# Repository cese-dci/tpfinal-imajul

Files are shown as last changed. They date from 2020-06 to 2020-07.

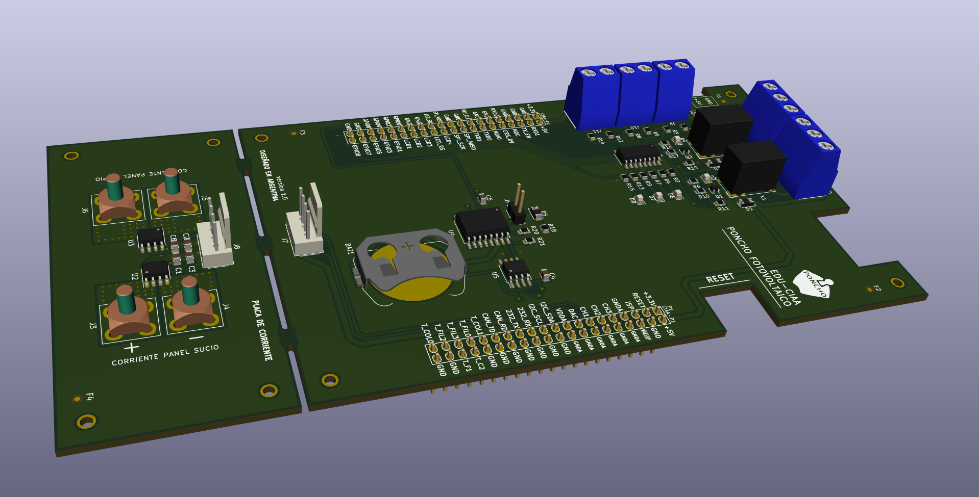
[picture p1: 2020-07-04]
PCB_3D.png

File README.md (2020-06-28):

# Diseño de circuitos impresos - TP Final

## Poncho EDU-CIAA para sistema de limpieza de paneles solares

El sistema que mide desposicion de suciedad sobre paneles en un parque solar fotovoltaico. El PCB recibe dos señales analógicas de corriente para ser procesadas, contendra salidas digitales libres de pontencial, entradas digitales, un RTC y una EEPROM sobre I2C.

### Requisitos

Este trabajo forma parte del proyecto final de especialización del autor - CESE 10ma cohorte.

## Autor

* **Ing. Ignacio Majul** - [imajul](https://github.com/imajul)

## Licencia

Este proyecto se rige bajo la licencia del Proyecto CIAA - ver license.md

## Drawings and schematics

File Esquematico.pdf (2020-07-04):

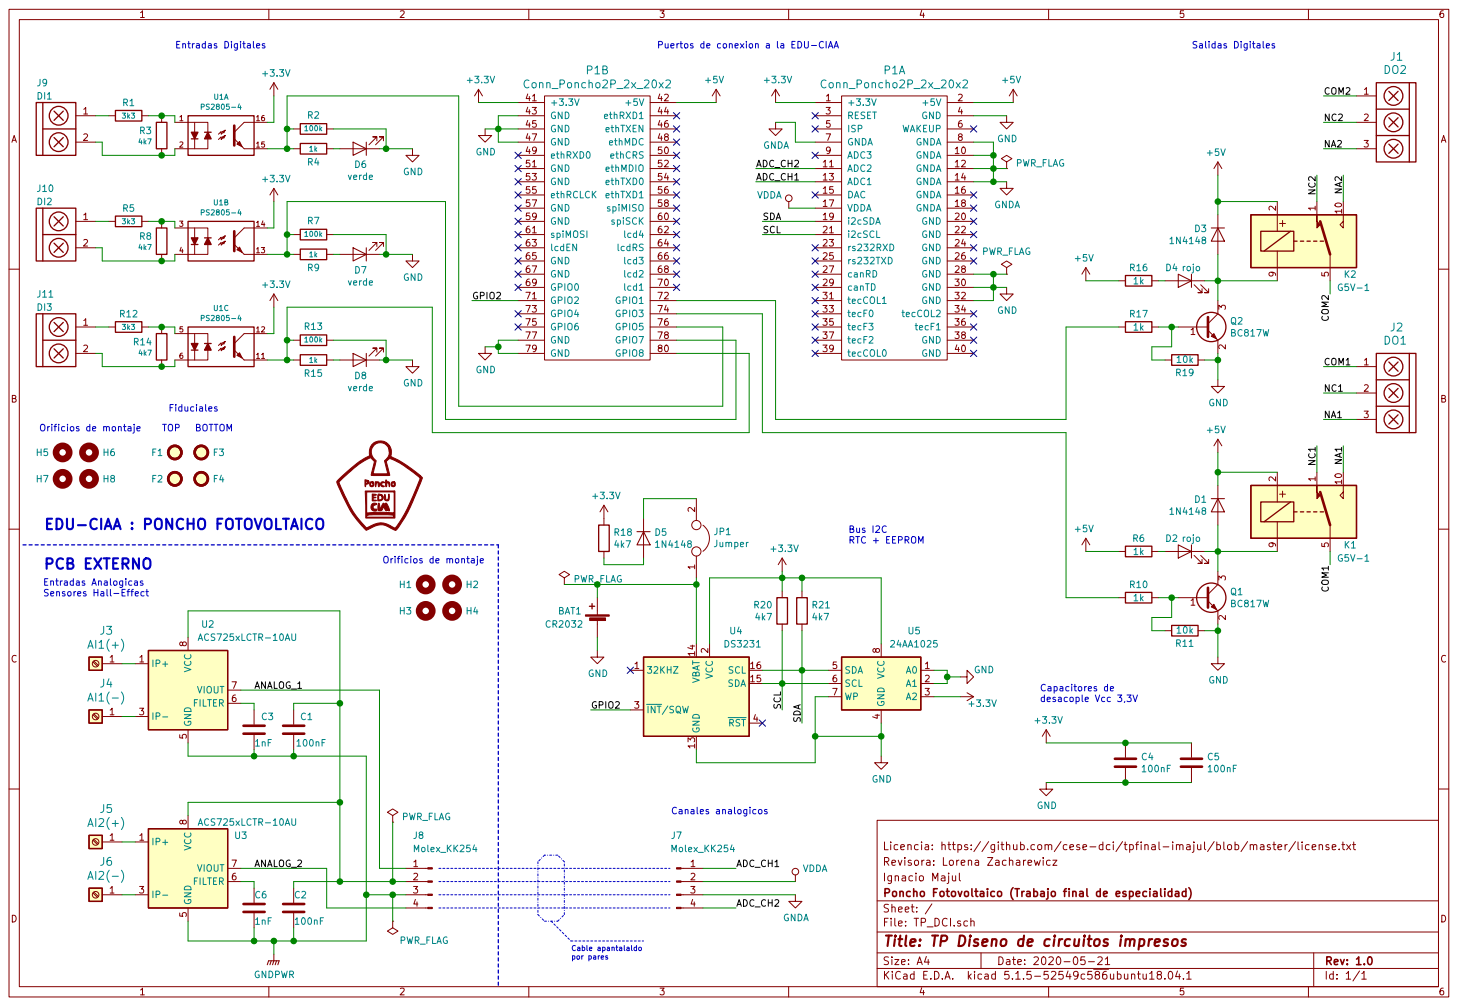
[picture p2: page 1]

EDU-CIAA : PONCHO FOTOVOLTAICO

por pares PCB EXTERNO

4 SDA 5 SCL 6 WP 7 VCC

Ignacio Majul Revisora: Lorena Zacharewicz Licencia: https://github.com/cese-dci/tpfinal-imajul/blob/master/license.txt

File: TP_DCI.sch Sheet: / Poncho Fotovoltaico (Trabajo final de especialidad)

Id: 1/1 Title: TP Diseno de circuitos impresos

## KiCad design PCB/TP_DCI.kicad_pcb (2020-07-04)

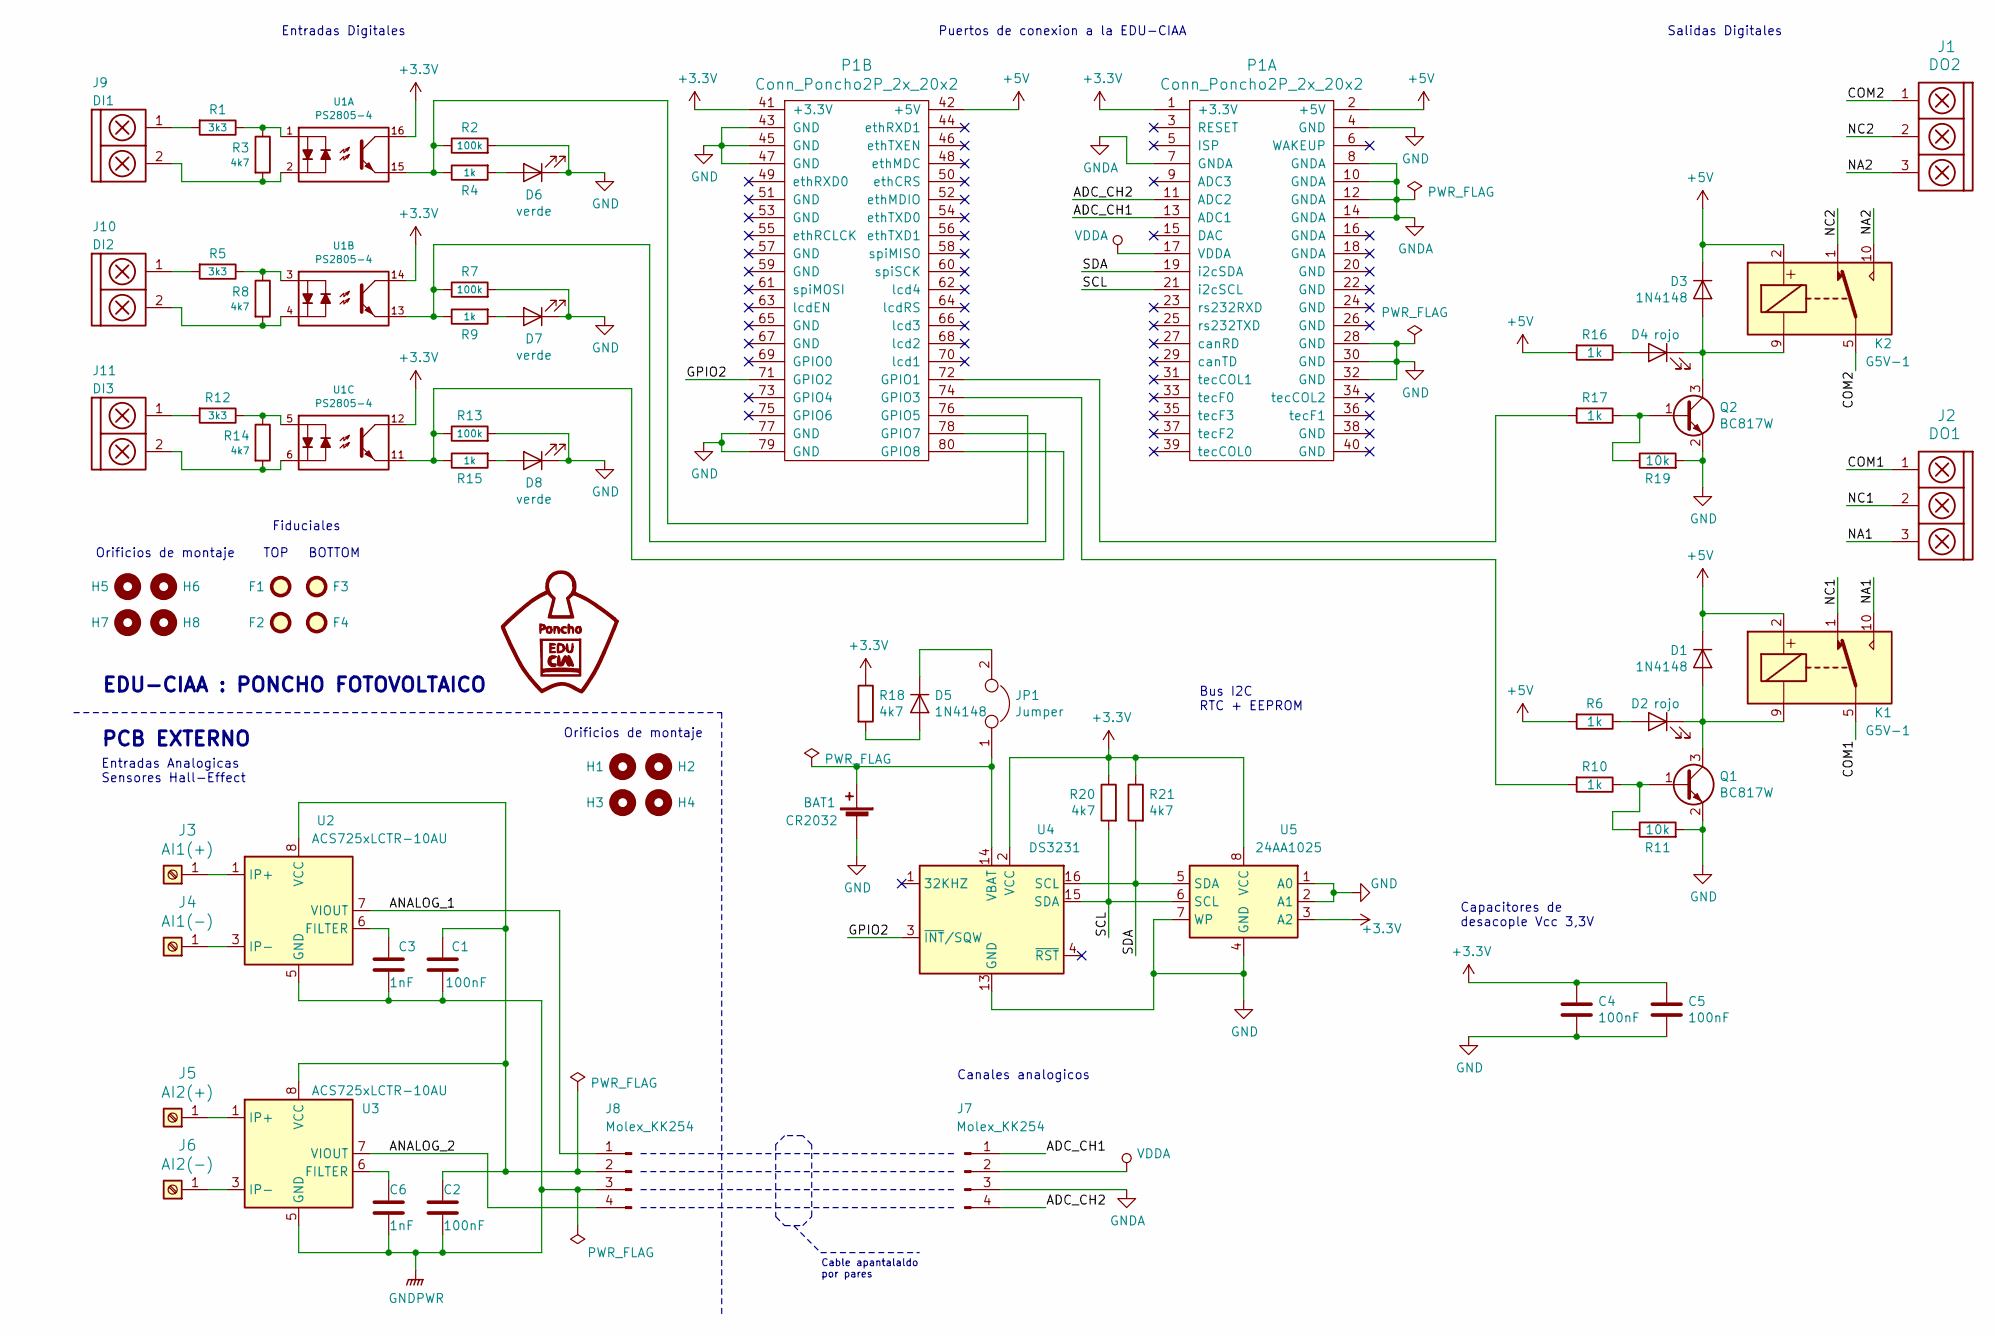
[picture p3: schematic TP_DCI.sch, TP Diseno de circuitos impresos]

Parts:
BAT1: CR2032; BatteryHolder_Keystone_3034_1x20mm
C1, C2, C4, C5: 100nF; C_0805_2012Metric
C3, C6: 1nF; C_0805_2012Metric
D1, D3, D5: 1N4148; D_1206_3216Metric
D2, D4: rojo; LED_0805_2012Metric
D6, D7, D8: verde; LED_0805_2012Metric
F1, F2, F3, F4: Fiducial; Fiducial_1mm_Mask2mm
G1: Logo_Poncho
H1, H2, H3, H4, H5, H6, H7, H8: MountingHole; MountingHole_2.1mm
J1: DO2; bornier3
J2: DO1; bornier3
J3: AI1(+); wurth_connector
J4: AI1(-); wurth_connector
J5: AI2(+); wurth_connector
J6: AI2(-); wurth_connector
J7, J8: Molex_KK254; Molex_KK-254_AE-6410-04A_1x04_P2.54mm_Vertical
J9: DI1; bornier2
J10: DI2; bornier2
J11: DI3; bornier2
JP1: Jumper; PinHeader_1x02_P2.54mm_Vertical
K1, K2: G5V-1; Relay_SPDT_Omron_G5V-1
P1: Conn_Poncho2P_2x_20x2; Conn_Poncho_SinBorde
Q1, Q2: BC817W; SOT-323_SC-70
R1, R5, R12: 3k3; R_0805_2012Metric
R2, R7, R13: 100k; R_0805_2012Metric
R3, R8, R14, R18, R20, R21: 4k7; R_0805_2012Metric
R4, R6, R9, R10, R15, R16, R17: 1k; R_0805_2012Metric
R11, R19: 10k; R_0805_2012Metric
U1: PS2805-4; SOP-16_4.4x10.4mm_P1.27mm
U2, U3: ACS725xLCTR-10AU; SOIC-8_3.9x4.9mm_P1.27mm
U4: DS3231; SOIC-16W_7.5x10.3mm_P1.27mm
U5: 24AA1025; SOIC-8_5.23x5.23mm_P1.27mm

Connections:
+3V3: C4.1, C5.1, P1.1 (+3.3V), P1.41 (+3.3V), R18.1, R20.1, R21.1, U1.12, U1.14, U1.16, U4.2 (VCC), U5.3 (A2), U5.8 (VCC)
+5V: D1.1 (K), D3.1 (K), K1.2, K2.2, P1.2 (+5V), P1.42 (+5V), R6.2, R16.2
/ADC_CH1: J7.1, P1.13 (ADC1)
/ADC_CH2: J7.4, P1.11 (ADC2)
/ANALOG_1: J8.1, U2.7 (VIOUT)
/ANALOG_2: J8.4, U3.7 (VIOUT)
/COM1: J2.1, K1.5, K1.6
/COM2: J1.1, K2.5, K2.6
/GPIO2: P1.71 (GPIO2), U4.3 (~INT~/SQW)
/NA1: J2.3, K1.10
/NA2: J1.3, K2.10
/NC1: J2.2, K1.1
/NC2: J1.2, K2.1
/SCL: P1.21 (i2cSCL), R20.2, U4.15 (SDA), U5.6 (SCL)
/SDA: P1.19 (i2cSDA), R21.2, U4.16 (SCL), U5.5 (SDA)
GND: BAT1.2 (-), C4.2, C5.2, D6.1 (K), D7.1 (K), D8.1 (K), P1.4 (GND), P1.28 (GND), P1.30 (GND), P1.32 (GND), P1.43 (GND), P1.45 (GND), P1.47 (GND), P1.77 (GND), P1.79 (GND), Q1.2 (E), Q2.2 (E), R2.2, R7.2, R11.2, R13.2, R19.2, U4.5 (GND), U4.6 (GND), U4.7 (GND), U4.8 (GND), U4.9 (GND), U4.10 (GND), U4.11 (GND), U4.12 (GND), U4.13 (GND), U5.1 (A0), U5.2 (A1), U5.4 (GND), U5.7 (WP)
unnamed: C3.1, U2.6 (FILTER)
unnamed: C6.1, U3.6 (FILTER)
unnamed: D1.2 (A), D2.1 (K), K1.9, Q1.3 (C)
unnamed: D2.2 (A), R6.1
unnamed: D3.2 (A), D4.1 (K), K2.9, Q2.3 (C)
unnamed: D4.2 (A), R16.1
unnamed: D5.1 (K), JP1.2
unnamed: D5.2 (A), R18.2
unnamed: D6.2 (A), R4.2
unnamed: D7.2 (A), R9.2
unnamed: D8.2 (A), R15.2
unnamed: J3.1, U2.1 (IP+), U2.2 (IP+)
unnamed: J4.1, U2.3 (IP-), U2.4 (IP-)
unnamed: J5.1, U3.1 (IP+), U3.2 (IP+)
unnamed: J6.1, U3.3 (IP-), U3.4 (IP-)
unnamed: J9.1, R1.2
unnamed: J9.2, R3.2, U1.2
unnamed: J10.1, R5.2
unnamed: J10.2, R8.2, U1.4
unnamed: J11.1, R12.2
unnamed: J11.2, R14.2, U1.6
unnamed: P1.72 (GPIO1), R17.2
unnamed: P1.74 (GPIO3), R10.2
unnamed: P1.76 (GPIO5), R2.1, R4.1, U1.15
unnamed: P1.78 (GPIO7), R7.1, R9.1, U1.13
unnamed: P1.80 (GPIO8), R13.1, R15.1, U1.11
unnamed: Q1.1 (B), R10.1, R11.1
unnamed: Q2.1 (B), R17.1, R19.1
unnamed: R1.1, R3.1, U1.1
unnamed: R5.1, R8.1, U1.3
unnamed: R12.1, R14.1, U1.5
VDDA: J7.2, P1.17 (VDDA)

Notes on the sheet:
Capacitores de desacople Vcc 3,3V
EDU-CIAA : PONCHO FOTOVOLTAICO
Canales analogicos
Entradas Analogicas Sensores Hall-Effect
Salidas Digitales
PCB EXTERNO
Bus I2C RTC + EEPROM
Orificios de montaje
BOTTOM
TOP
Fiduciales
Cable apantalaldo por pares
Entradas Digitales
Puertos de conexion a la EDU-CIAA

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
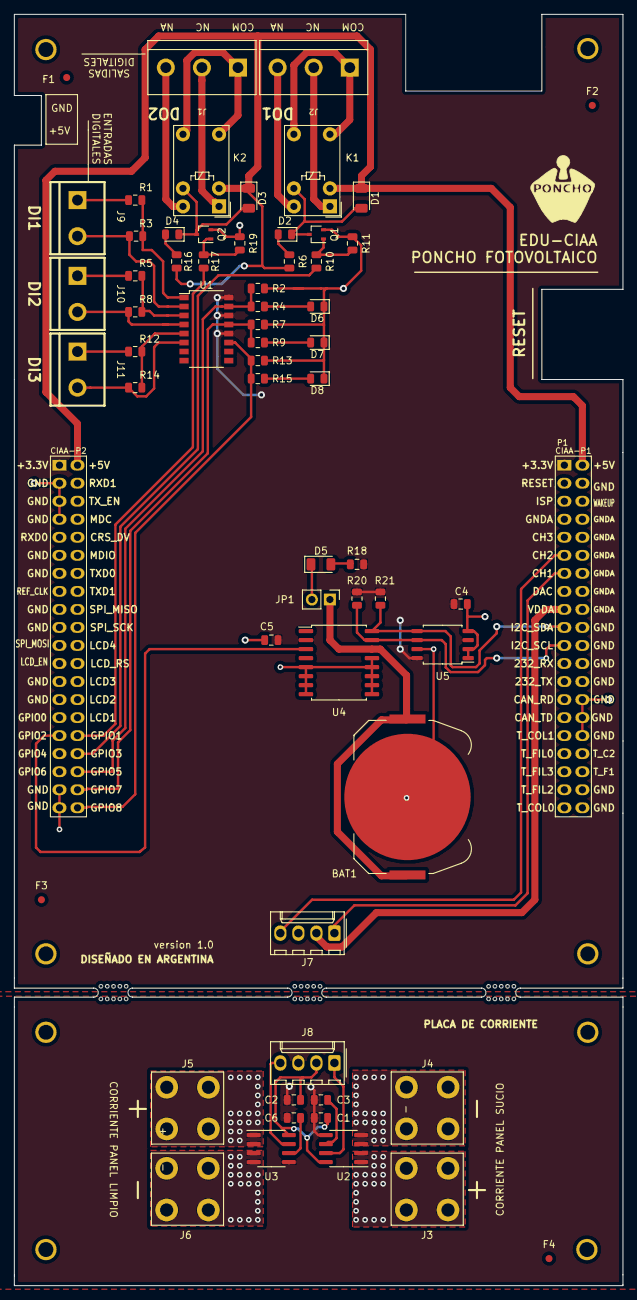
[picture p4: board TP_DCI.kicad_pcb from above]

Board: 2 copper layers, 85.7 x 179.1 mm, 71 parts (0 on the bottom side), 52 nets.

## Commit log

2020-06-01 Primer commit con esquematico
    [TP_DCI.dxf, TP_DCI.kicad_pcb, TP_DCI.sch]
2020-06-01 correcion de footprints
2020-06-01 correccion de footprints
    [TP_DCI.sch]
2020-06-01 nuevo PDF y DXF del esquematico
    [TP_DCI.dxf]
2020-06-02 Se incorpora plantilla de poncho EDU-CIAA
    [TP_DCI.kicad_pcb, TP_DCI.sch]
2020-06-02 actualizacion de footprints y 3Dshapes
    [TP_DCI.kicad_pcb, TP_DCI.sch]
2020-06-02 se agrega figura 3D de borneras
2020-06-06 actualizacion de footprint de sensor de corriente
2020-06-06 se agregar footprint de bornera de corriente
2020-06-06 se agrega datasheet de bornera de corriente
2020-06-06 actualizacion de esquematico con nuevos componentes, se agregan vias termicas en PCB
    [Hall_effect_sensors.sch, Poncho_fotovoltaico.sch, TP_DCI.kicad_pcb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]
2020-06-06 acomodo leyendas superpuestas
    [TP_DCI.sch]
2020-06-09 agrego footprints CIAA
2020-06-09 correcciones en rotulo de acuerdo a sugerencias del revisor
    [TP_DCI.sch]
2020-06-27 actualizaciones de esquematico segun correcciones del docente
    [TP_DCI.kicad_pcb, TP_DCI.sch]
2020-06-28 avances en ruteo del PCB
    [TP_DCI.kicad_pcb, TP_DCI.sch]
2020-06-28 corrijo licencia
    [TP_DCI.sch]
2020-06-28 Agrego imagen 3D del PCB
2020-06-28 modifico imagen 3D del PCB
    [TP_DCI.dxf]
2020-07-04 Correcciones segun sugerencias del docente
    - se incremento el ancho de tracks, tamaño de vias y clearance.
    - el tamaño amplio del poncho se justifica por cuestiones mecánicas, para lograr mas puntos de anclaje a la EDU-CIAA
    - se agregan comentarios para el fabricante.
    [TP_DCI.kicad_pcb, TP_DCI.sch]
